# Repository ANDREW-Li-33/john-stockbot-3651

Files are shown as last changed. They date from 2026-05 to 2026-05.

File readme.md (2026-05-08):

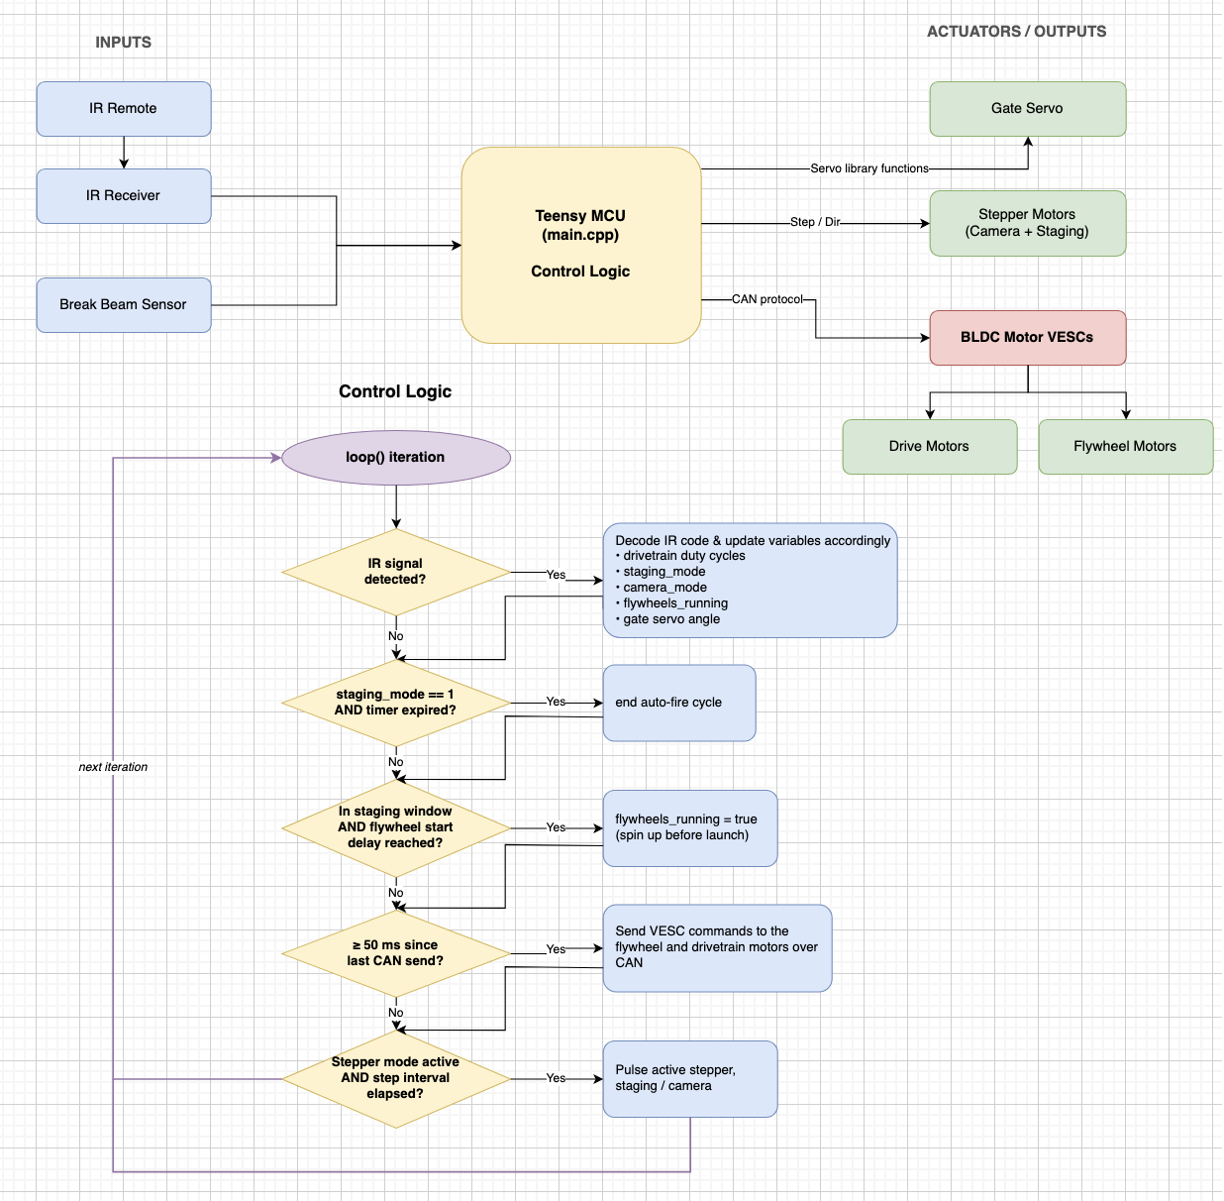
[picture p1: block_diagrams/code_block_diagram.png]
code block diagram

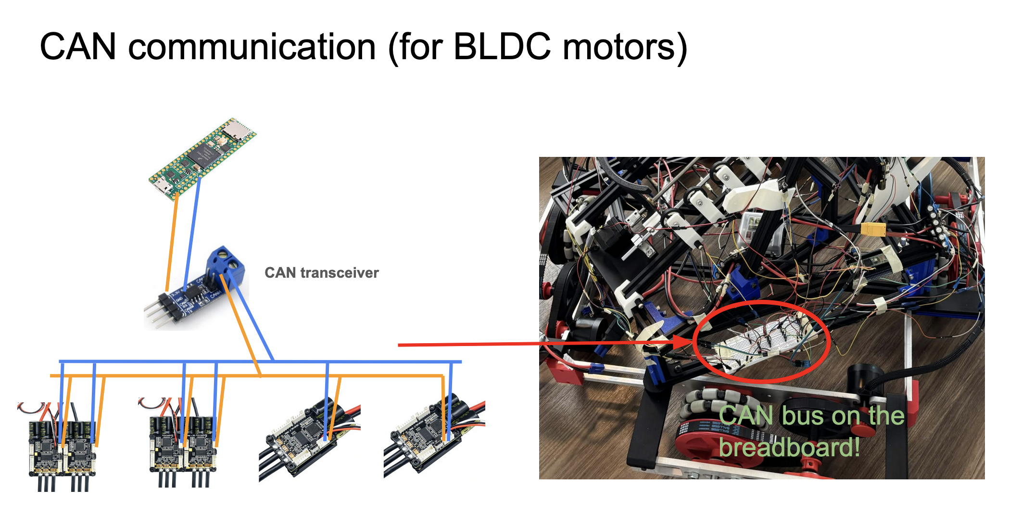
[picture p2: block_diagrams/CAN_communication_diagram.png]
CAN communication block diagram

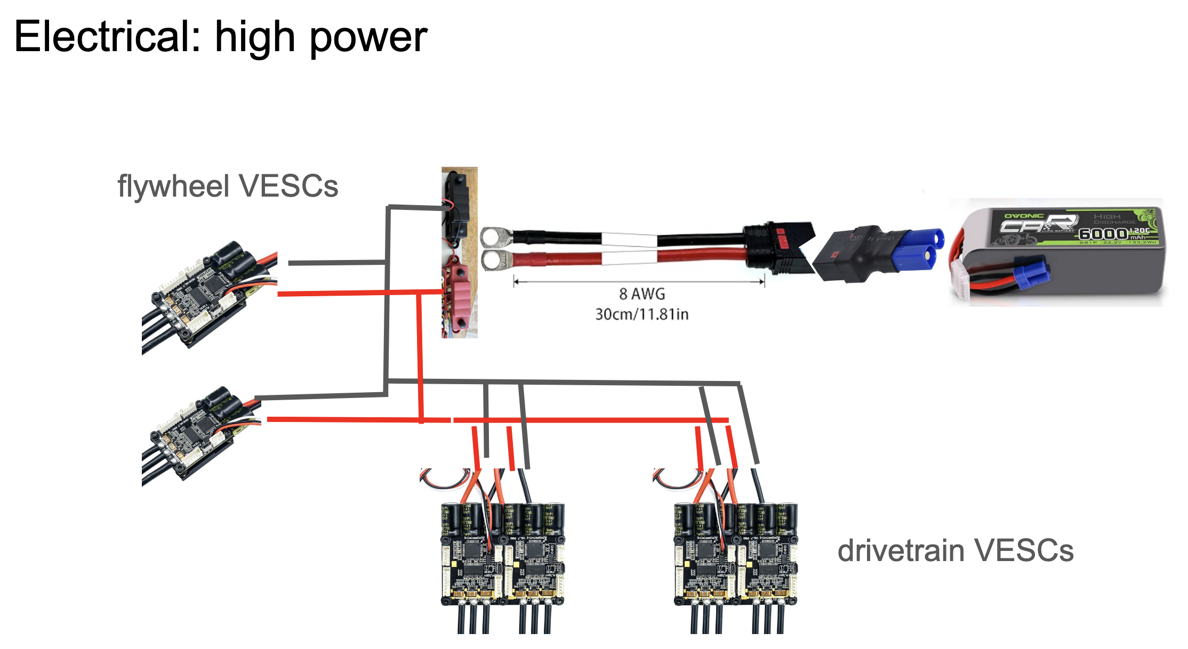
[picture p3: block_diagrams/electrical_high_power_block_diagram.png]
electrical high power block diagram

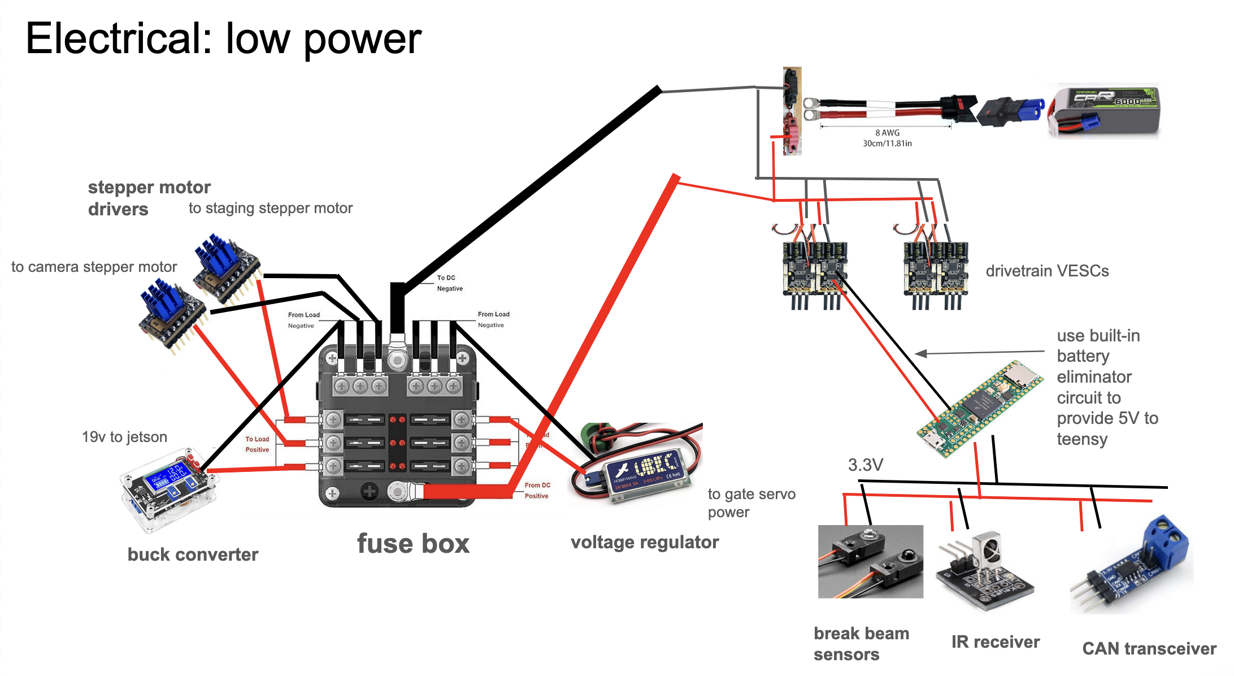
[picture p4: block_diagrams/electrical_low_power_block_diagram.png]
electrical low power block diagram


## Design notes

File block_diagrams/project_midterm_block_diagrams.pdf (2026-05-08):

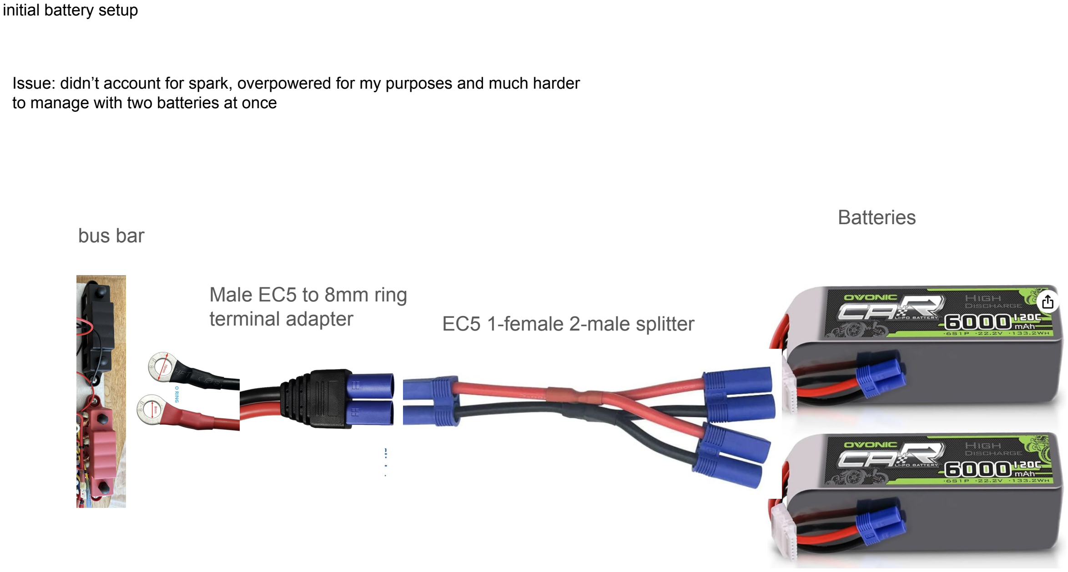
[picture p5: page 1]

initial battery setup

### Male EC5 to 8mm ring terminal adapter

### Batteries

### EC5 1-female 2-male splitter

### bus bar

Issue: didn’t account for spark, overpowered for my purposes and much harder to manage with two batteries at once

## new battery setup:

## - battery -> ec5 female - ec5 male -> QS8-S female - QS8-S female-> QS8-S male - QS8-S female -> ring terminal - ring terminal -> bus bar

# drivetrain escs to bus bar:

# - XT90 to ring terminal

# flywheel escs to bus bar:

# - bare wire to ring terminal - ring terminal to bus bar

# new battery setup

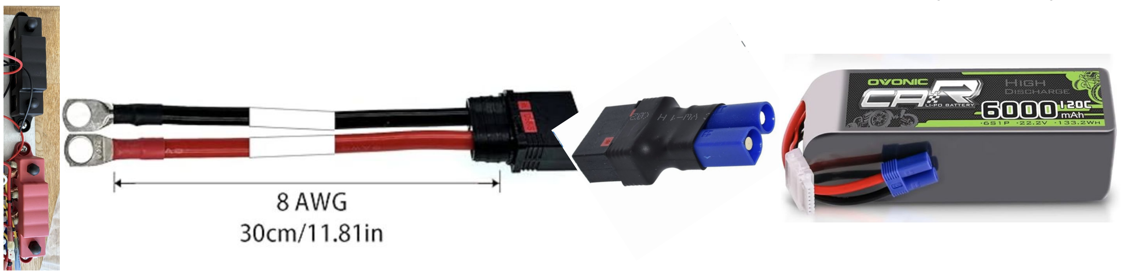
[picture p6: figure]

only one battery

QS8-S connectors.

- built-in anti-spark
- rated for up to 300A continuous

# New power distribution setup

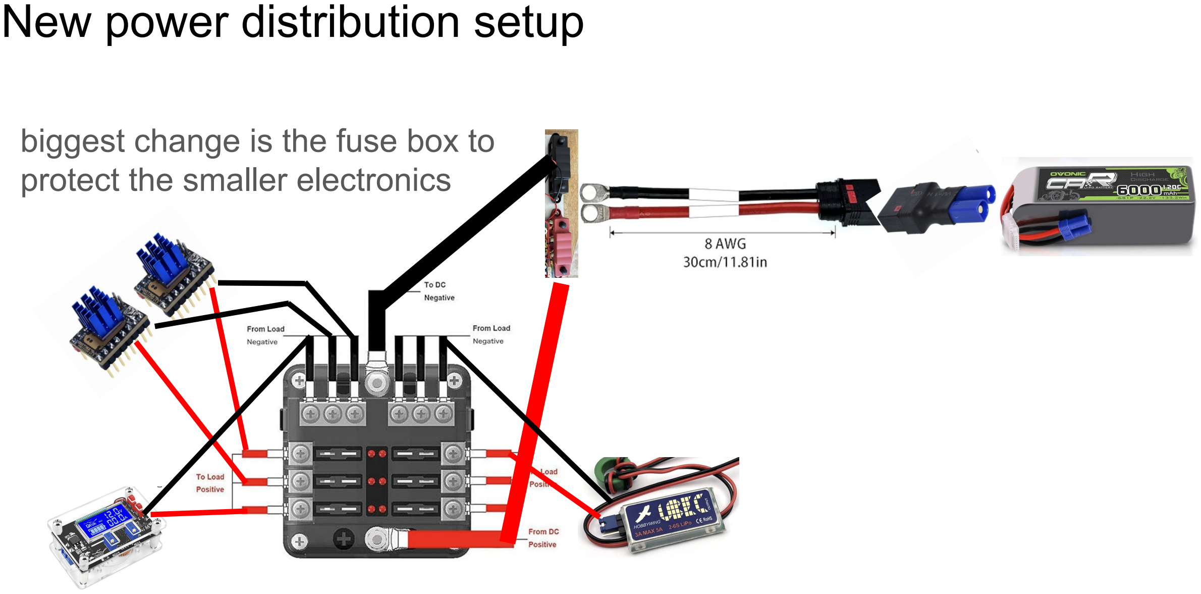
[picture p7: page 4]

# biggest change is the fuse box to protect the smaller electronics

# cut the copper trace between Vin and Vusb on the teensy so that i can have the battery powering the teensy and view the serial output through usb at the same time

# from laptop

## note: use protoboard and dupont connectors

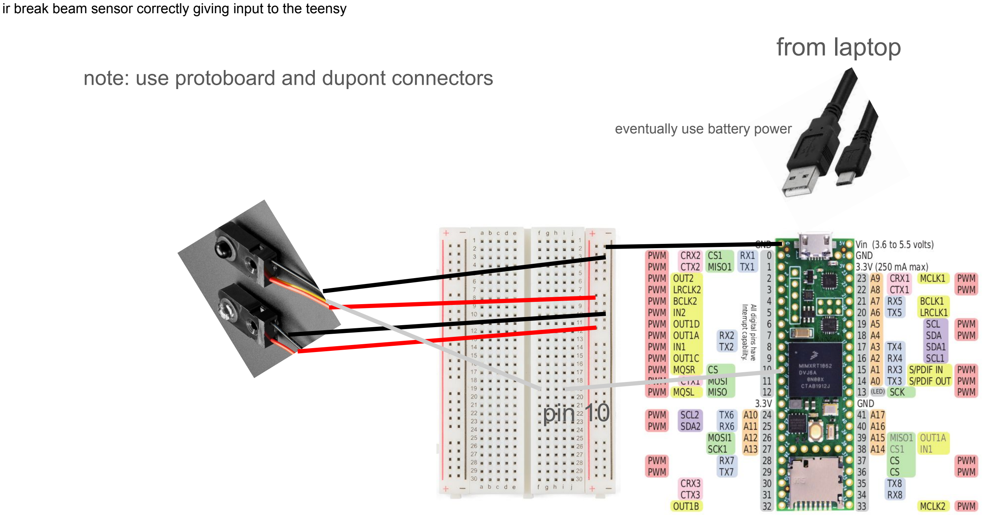
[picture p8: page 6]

ir break beam sensor correctly giving input to the teensy

# pin 10

eventually use battery power

## remote control working with the teensy

# from laptop

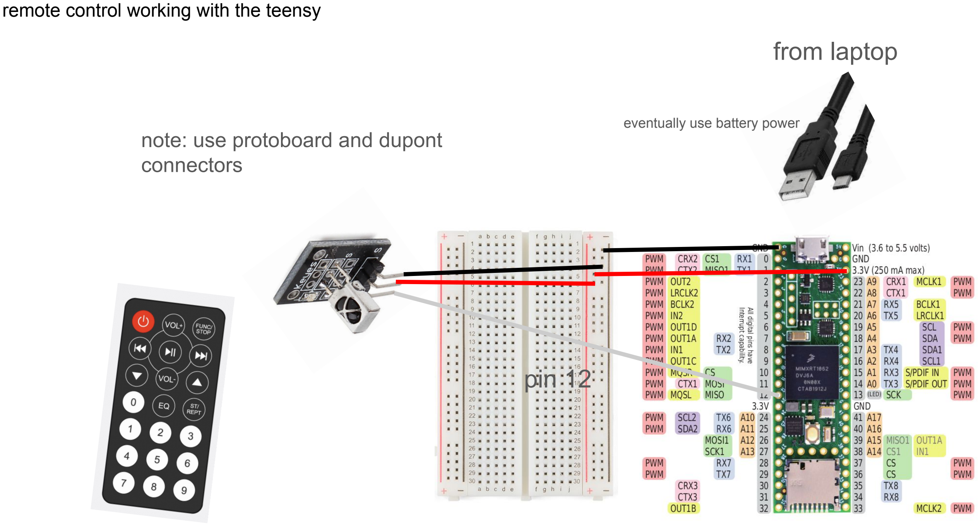
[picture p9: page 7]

# pin 12

eventually use battery power

## note: use protoboard and dupont connectors

## The servo motor moving using the remote control

## note: use protoboard and dupont

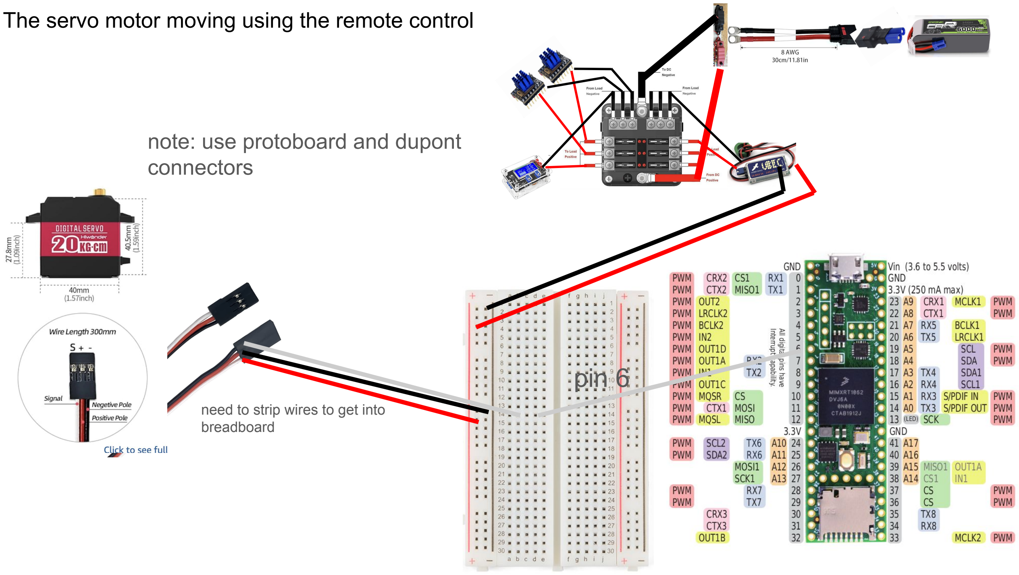
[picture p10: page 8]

need to strip wires to get into breadboard

# pin 6

## connectors

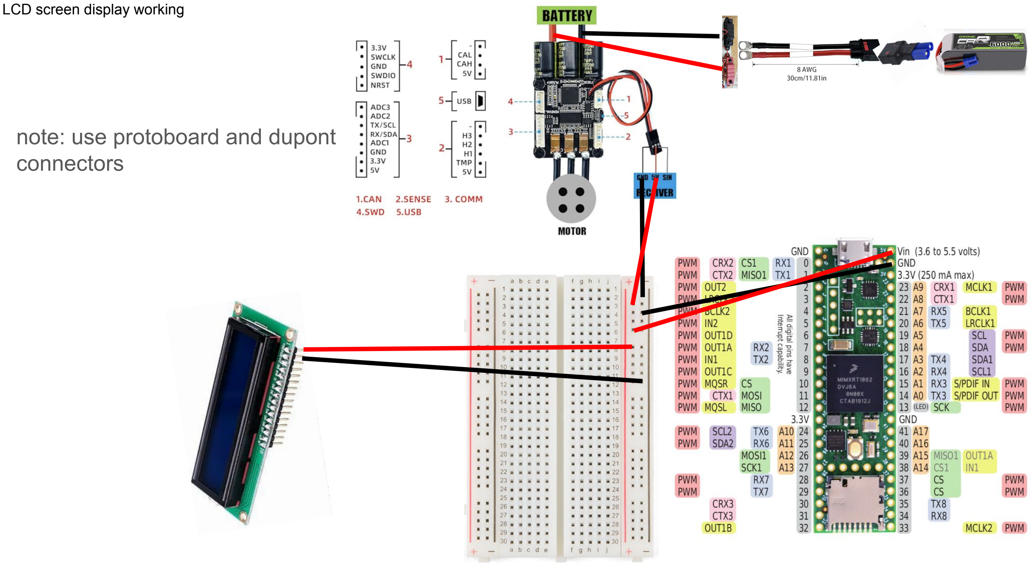
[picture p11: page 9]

LCD screen display working

## note: use protoboard and dupont connectors

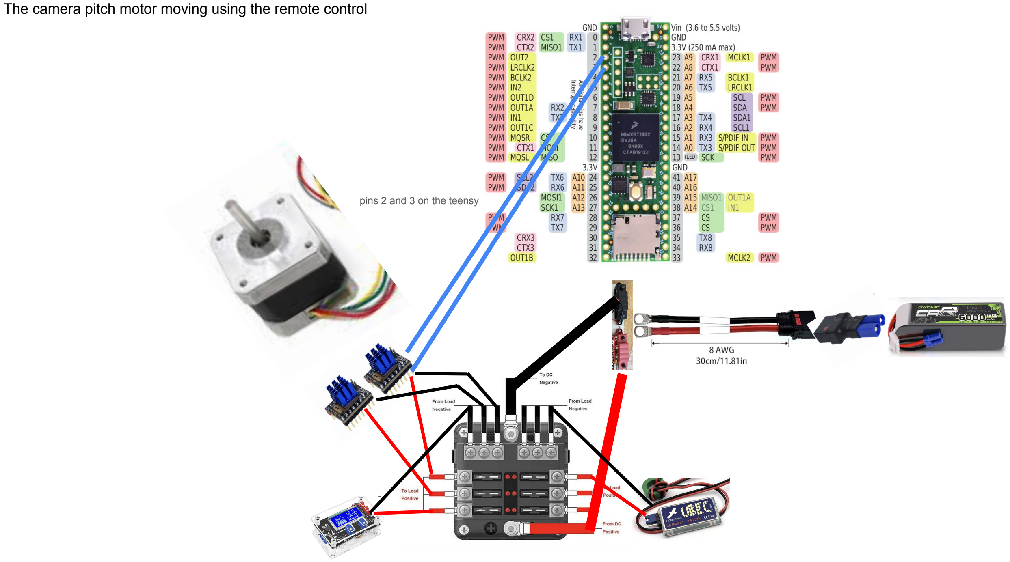
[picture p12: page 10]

The camera pitch motor moving using the remote control

pins 2 and 3 on the teensy

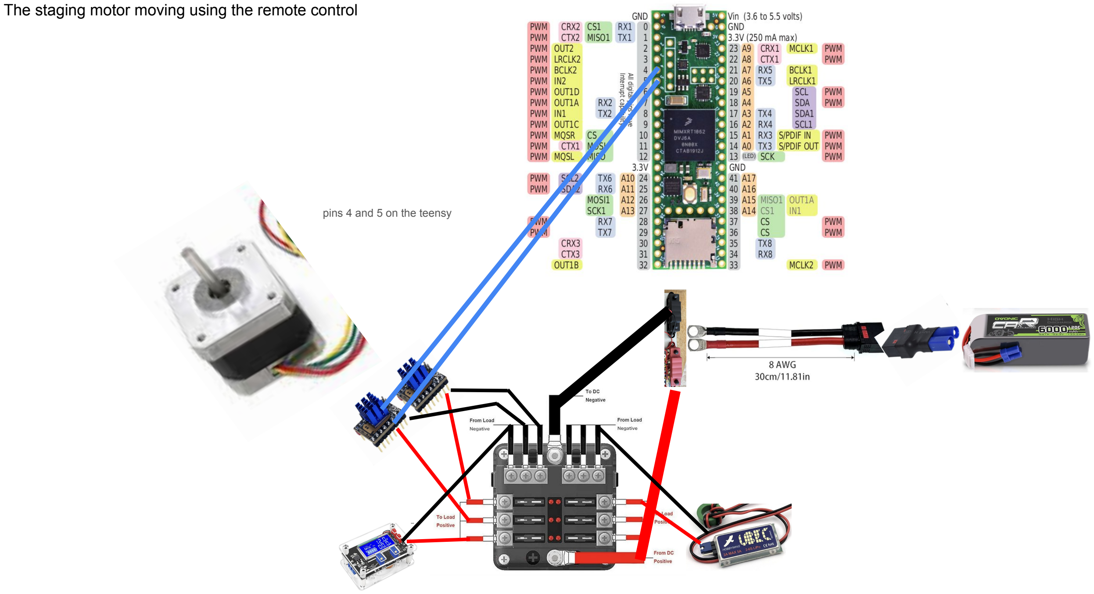
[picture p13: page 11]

The staging motor moving using the remote control

pins 4 and 5 on the teensy

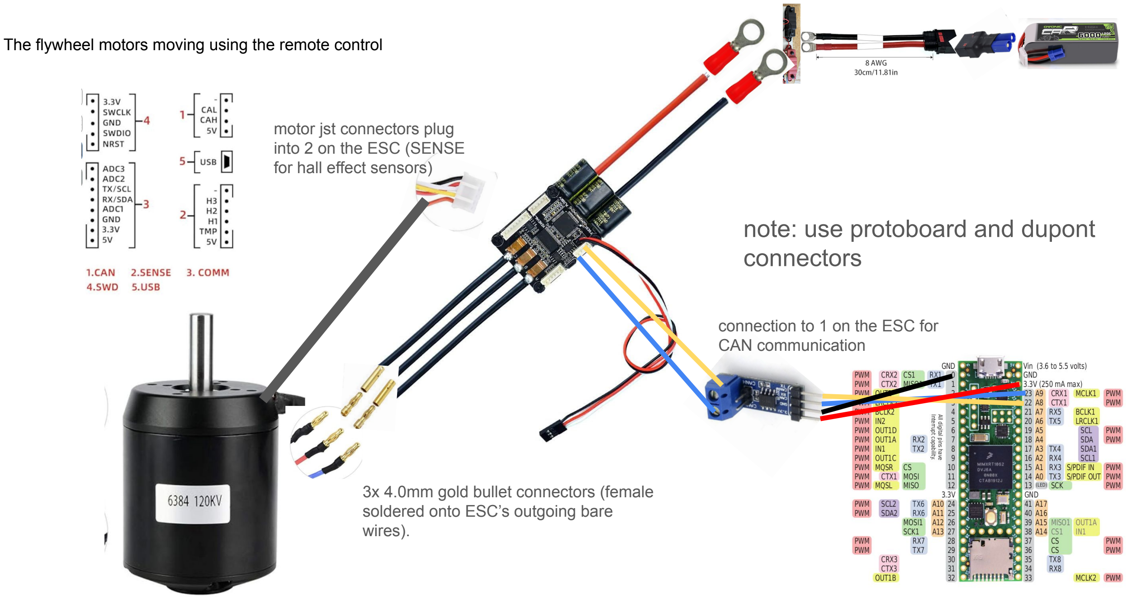
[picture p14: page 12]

The flywheel motors moving using the remote control

3x 4.0mm gold bullet connectors (female soldered onto ESC’s outgoing bare wires).

motor jst connectors plug
into 2 on the ESC (SENSE
for hall effect sensors)

connection to 1 on the ESC for CAN communication

## note: use protoboard and dupont connectors

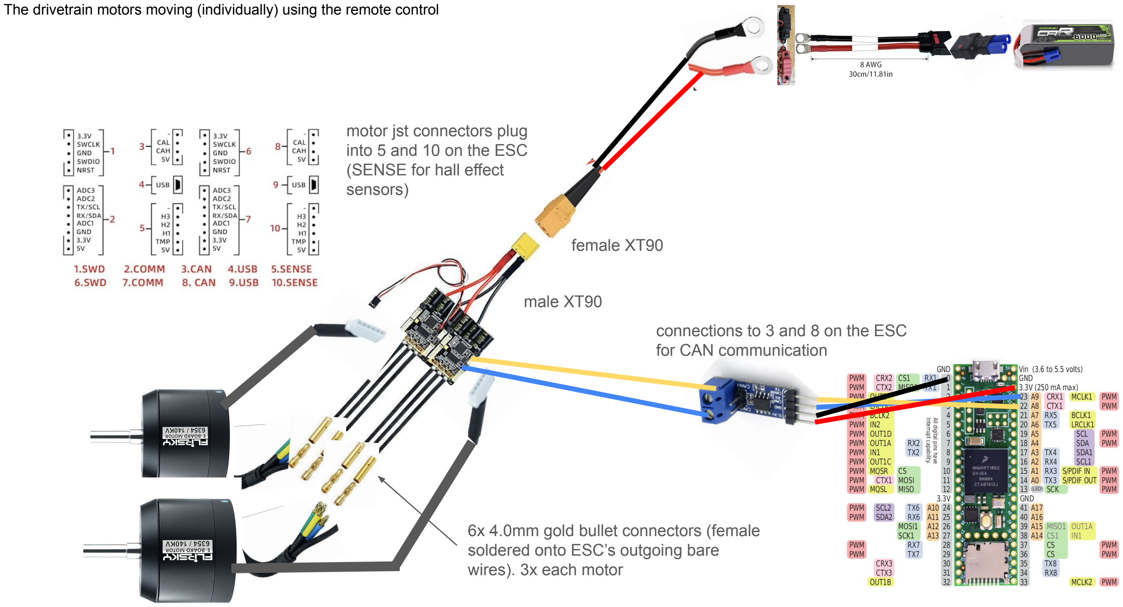
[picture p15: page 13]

The drivetrain motors moving (individually) using the remote control

male XT90

female XT90

6x 4.0mm gold bullet connectors (female soldered onto ESC’s outgoing bare wires). 3x each motor

motor jst connectors plug
into 5 and 10 on the ESC
(SENSE for hall effect
sensors)

connections to 3 and 8 on the ESC for CAN communication

# stepper motor driver connections (camera pitch controller)

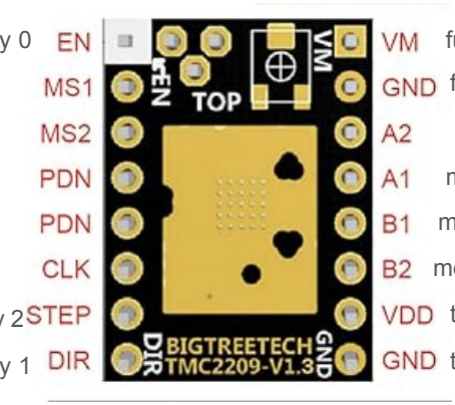
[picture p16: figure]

# fuse box

# fuse box

# teensy 3.3V

# teensy

# motor blue

# motor green

# motor red

# motor black

# teensy 1

# teensy 2

# teensy 0

# stepper motor driver connections (staging controller)

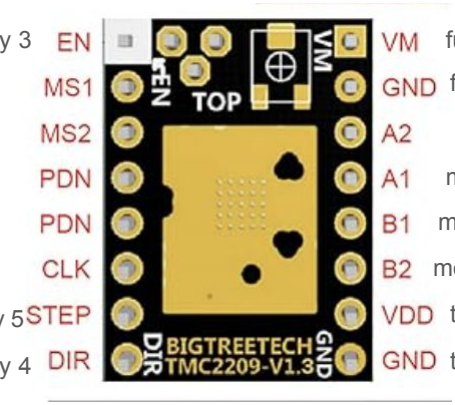
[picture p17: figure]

# fuse box

# fuse box

# teensy 3.3V

# teensy

# motor blue

# motor green

# motor red

# motor black

# teensy 4

# teensy 5

# teensy 3

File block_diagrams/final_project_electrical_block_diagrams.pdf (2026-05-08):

# Electrical: high power

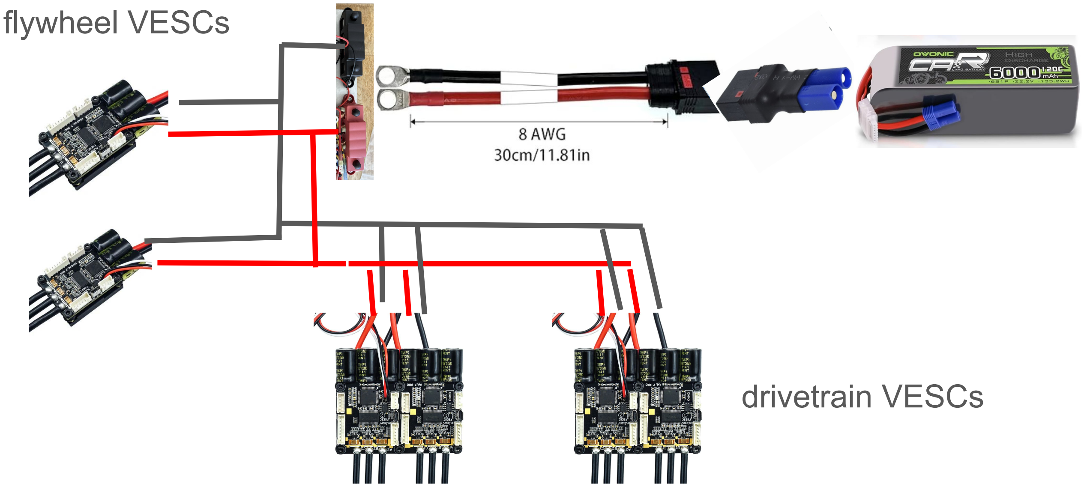
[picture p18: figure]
flywheel VESCs; drivetrain VESCs

# Electrical: low power

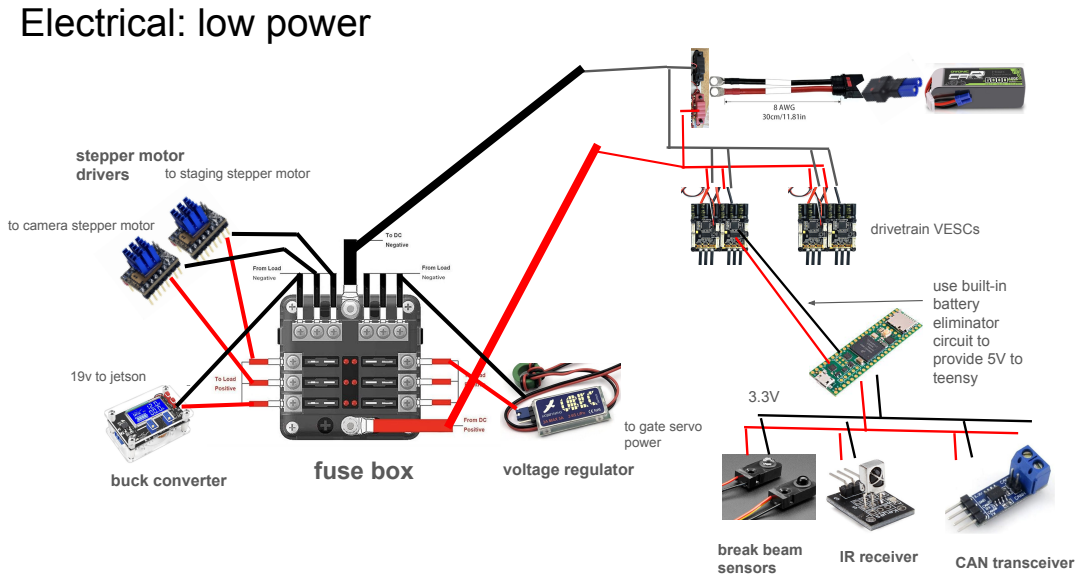
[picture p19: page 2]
drivetrain VESCs; 19v to jetson; stepper motor drivers; voltage regulator

to staging stepper motor

to camera stepper motor

use built-in
battery
eliminator
circuit to
provide 5V to
teensy

to gate servo
power

fuse box buck converter

CAN transceiver IR receiver break beam
sensors

# CAN communication (for BLDC motors)

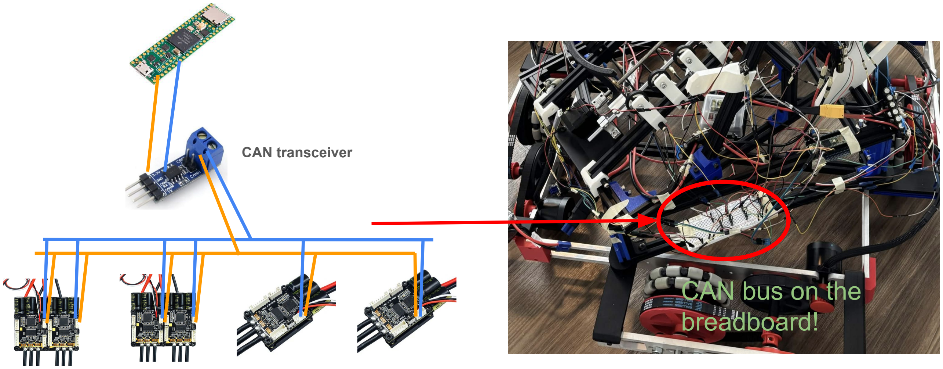
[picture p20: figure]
CAN transceiver; CAN bus on the breadboard!

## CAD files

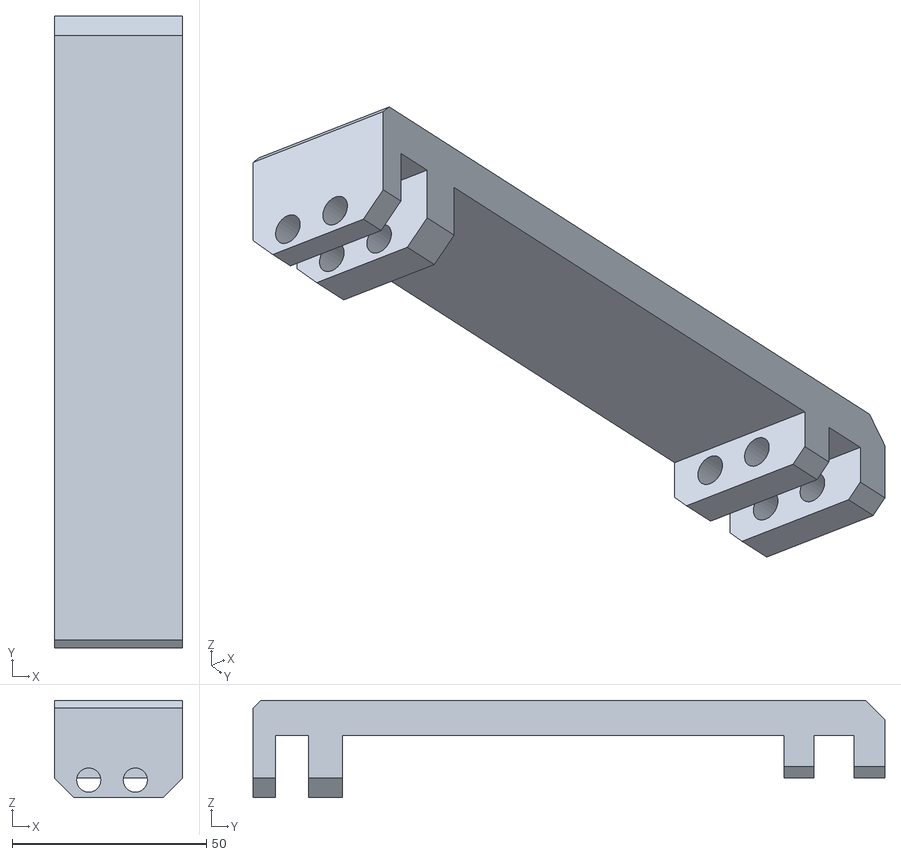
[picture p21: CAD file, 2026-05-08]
CAD files/drivetrain printed parts/large_motor_side_connector.stl
33.0 x 162.7 x 25.0

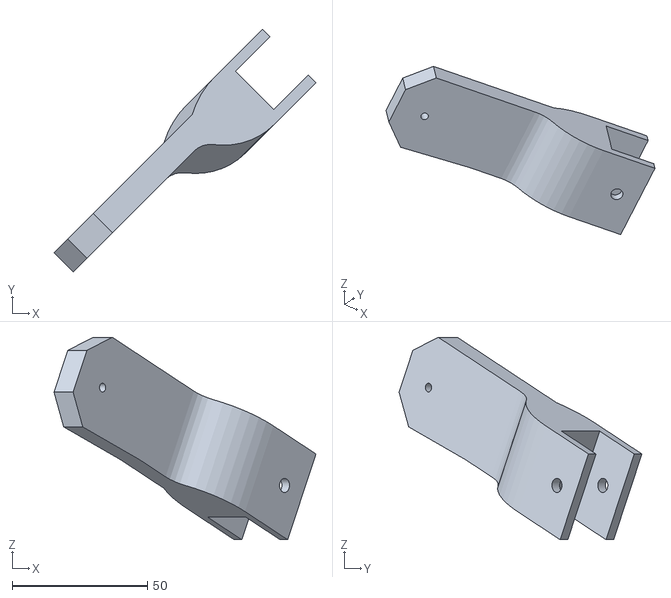
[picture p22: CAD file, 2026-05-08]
CAD files/final project 3651/break_beam_mount.stl
96.9 x 89.9 x 74.9

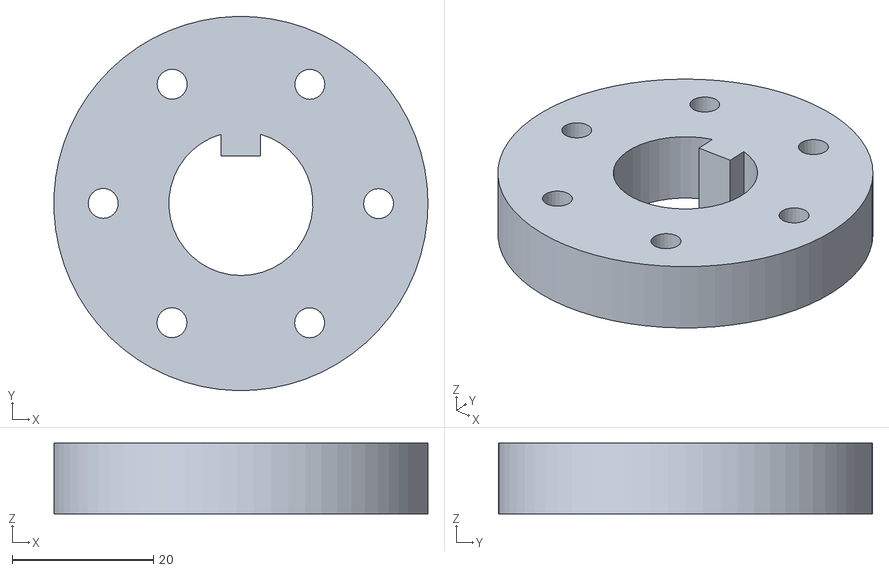
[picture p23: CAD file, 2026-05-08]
CAD files/flywheel printed parts/wheel attachment.stl
53.0 x 53.0 x 10.0

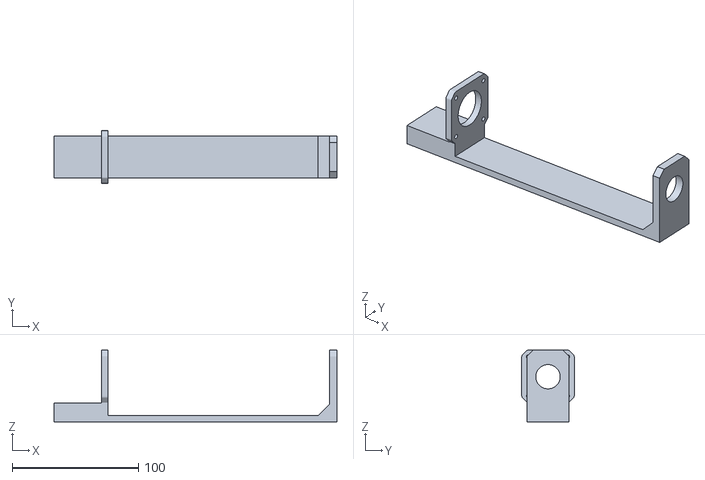
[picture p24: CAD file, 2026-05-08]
CAD files/john-stockbot-3dprint_camera/base.stl
224.2 x 41.6 x 56.8

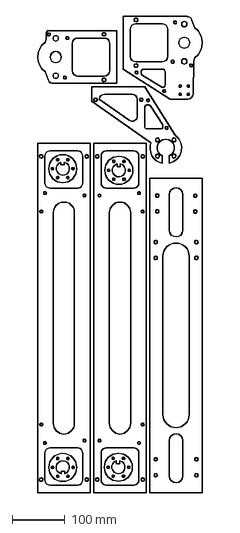
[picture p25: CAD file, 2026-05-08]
CAD files/john_stockbot_waterjet/sketch_no_points.dxf
312.7 x 903.2 mm

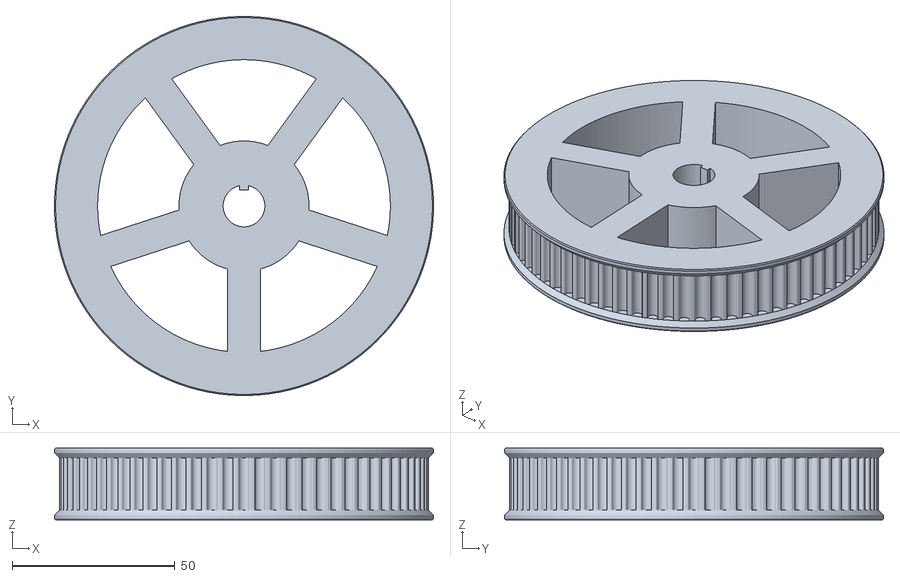
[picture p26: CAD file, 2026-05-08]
CAD files/drivetrain printed parts/intermediate_72T_pulley.stl
116.6 x 116.6 x 22.0

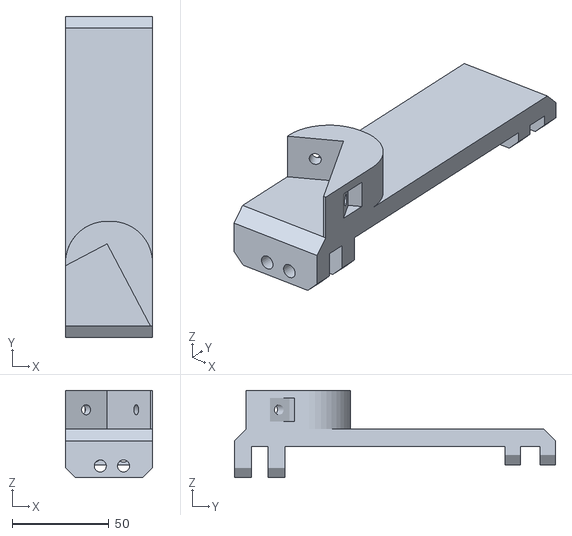
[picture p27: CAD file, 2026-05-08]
CAD files/final project 3651/thick outer plate.stl
45.0 x 165.7 x 45.0

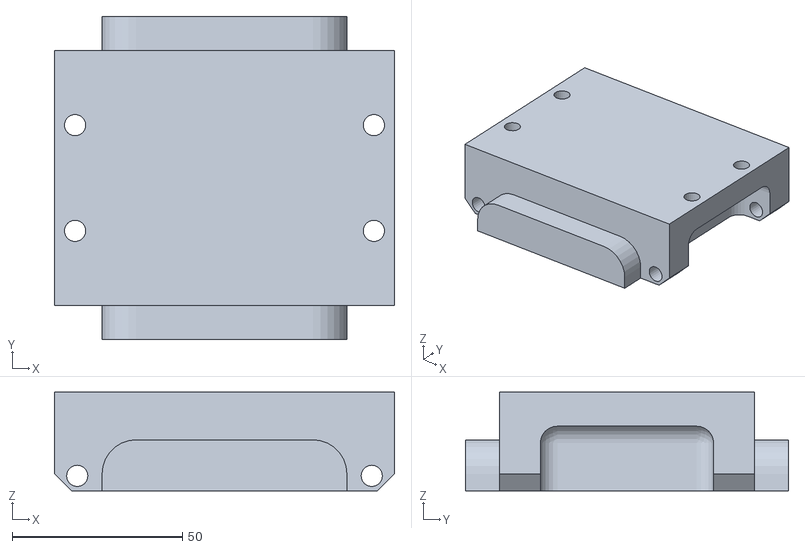
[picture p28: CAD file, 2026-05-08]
CAD files/flywheel printed parts/no motor side bracket.stl
100.0 x 95.0 x 29.0

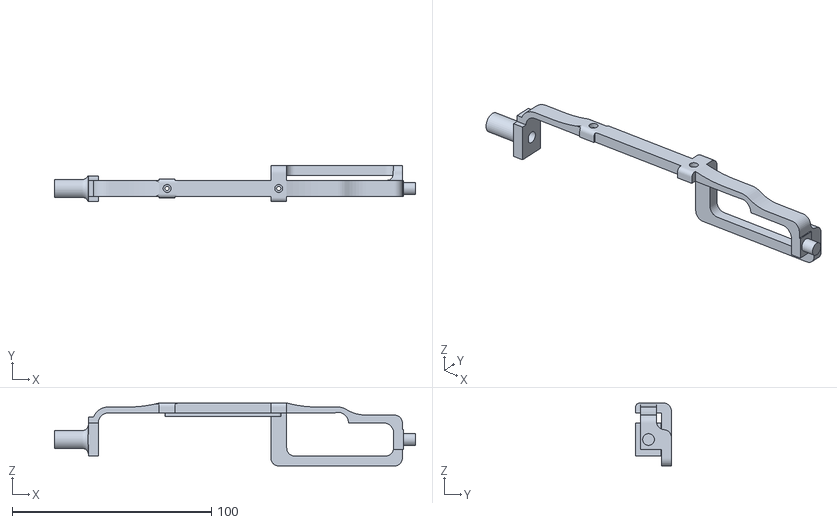
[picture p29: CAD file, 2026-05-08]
CAD files/john-stockbot-3dprint_camera/camera_attachment.stl
181.2 x 18.0 x 31.6

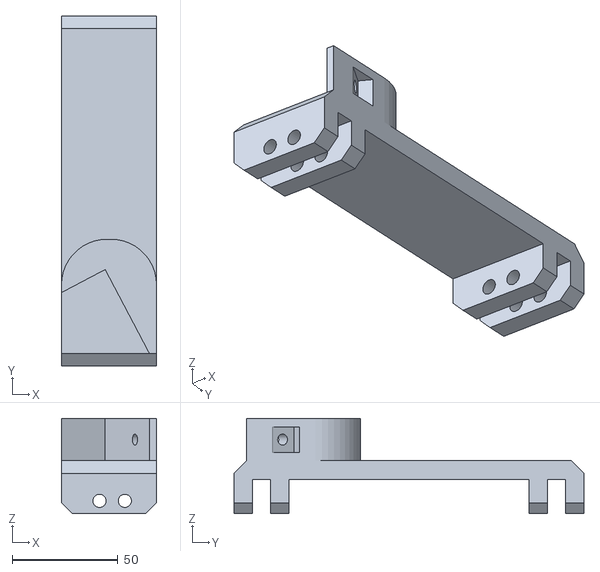
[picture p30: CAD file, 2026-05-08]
CAD files/drivetrain printed parts/small_non_motor_side_connector.stl
45.0 x 165.7 x 45.0

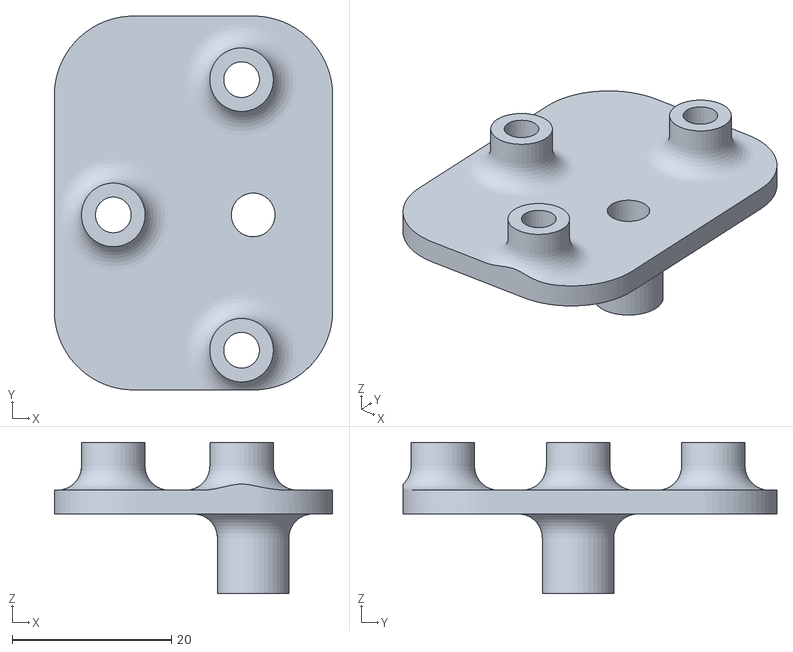
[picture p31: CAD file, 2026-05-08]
CAD files/final project 3651/single_esc_testing_plate.stl
35.0 x 47.0 x 19.0

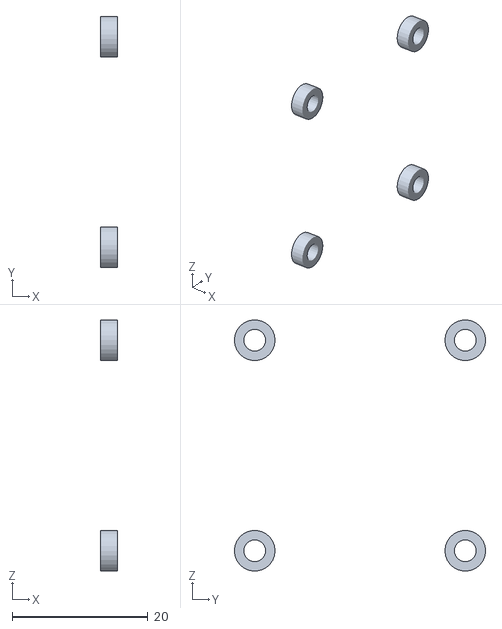
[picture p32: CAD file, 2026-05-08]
CAD files/john-stockbot-3dprint_camera/spaceres.stl
2.50 x 37.0 x 37.0

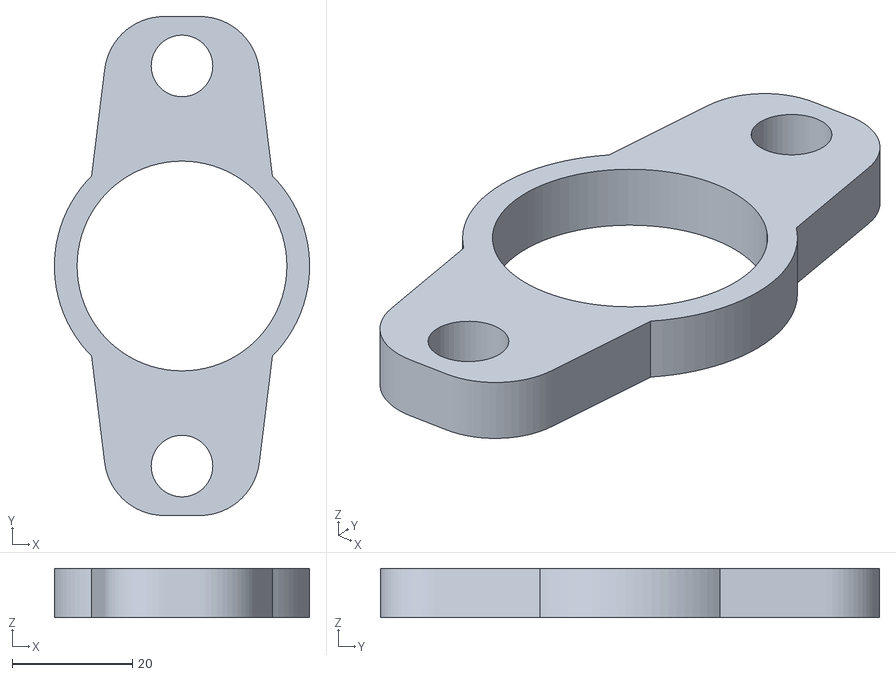
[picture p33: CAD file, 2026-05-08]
CAD files/drivetrain printed parts/ball bearing mount.stl
42.5 x 83.1 x 8.20

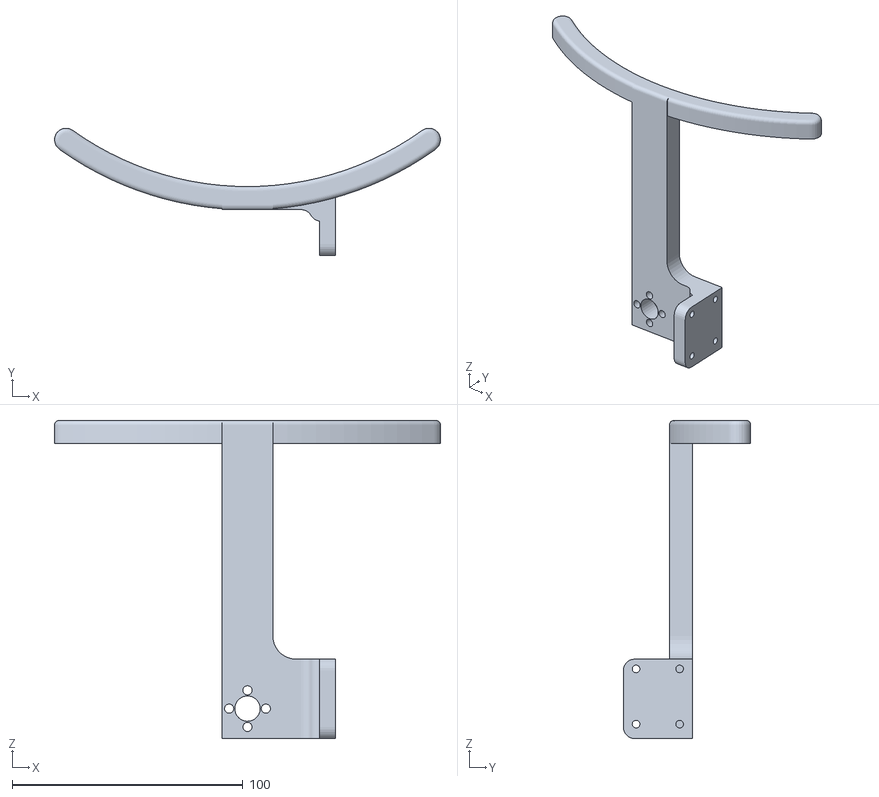
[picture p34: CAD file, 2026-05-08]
CAD files/final project 3651/push stick.stl
167.4 x 55.3 x 138.0

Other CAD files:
CAD files/flywheel printed parts/motor side inner bracket.stl
CAD files/drivetrain printed parts/wheel_90T_pulley.stl
CAD files/final project 3651/lighter_converyor_wheel.stl
CAD files/drivetrain printed parts/4mm_high_spacer.stl
CAD files/drivetrain printed parts/intermediate_20T_pulley.stl
CAD files/drivetrain printed parts/large_non_motor_side_connector.stl
CAD files/final project 3651/battery_mount.stl
CAD files/final project 3651/bottom_conveyor_mount.stl
CAD files/final project 3651/bus_bar_holder.stl
CAD files/final project 3651/conveyor_mount.stl
CAD files/final project 3651/conveyor_wheel.stl
CAD files/final project 3651/dual_drivetrain_esc_testing_plate.stl
CAD files/final project 3651/fuse_box_mount.stl
CAD files/final project 3651/gate_stick.stl
CAD files/final project 3651/lighter_converyor_wheel.f3d
CAD files/final project 3651/m5_spacer.stl
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

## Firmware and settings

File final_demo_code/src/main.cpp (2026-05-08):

#include <Arduino.h>
#include <FlexCAN_T4.h>
#include <Servo.h>

const byte TEENSY_LED_PIN = 13; // used for debugging break beam sensor

// SENSORS
const byte IR_RECEIVER_PIN = 12;
const byte BREAK_BEAM_PIN = 10;



// ACTUATION
const byte SERVO_PIN = 6;

// camera stepper motor
const byte CAM_STEPPER_EN_PIN = 0;
const byte CAM_STEPPER_DIR_PIN = 1;
const byte CAM_STEPPER_STEP_PIN = 2;

// staging stepper motor
const byte STAGE_STEPPER_EN_PIN = 3;
const byte STAGE_STEPPER_DIR_PIN = 4;
const byte STAGE_STEPPER_STEP_PIN = 5;


// BLDC motor control (flywheel and drivetrain)
const uint32_t CAN_PACKET_DUTY_CYCLE = 0;
const uint32_t CAN_PACKET_CURRENT = 1;

const byte TOP_FLY_CAN_ADDR = 27;
const byte BOT_FLY_CAN_ADDR = 91;

const byte DRIVE_FR_CAN_ADDR = 84;
const byte DRIVE_BL_CAN_ADDR = 79;
const byte DRIVE_FL_CAN_ADDR = 94;
const byte DRIVE_BR_CAN_ADDR = 72;

float duty_drive_FR = 0.0;
float duty_drive_BL = 0.0;
float duty_drive_FL = 0.0;
float duty_drive_BR = 0.0;

bool flywheels_running = false;

// durations in milliseconds
const uint16_t FLYWHEEL_START_DELAY = 26000;
const unsigned long STAGING_FORWARD_DURATION = 33000;

uint8_t staging_mode = 0;
unsigned long staging_forward_stop_time = 0; // the time in the future when the staging motor should stop

uint8_t camera_mode = 0;
unsigned long last_camera_step_time = 0;

unsigned long last_step_time = 0;
const unsigned long STEP_INTERVAL = 800;

// CAN communication with the BLDC motors
unsigned long lastCanSend = 0;
const unsigned long CAN_INTERVAL = 50;


FlexCAN_T4<CAN1, RX_SIZE_256, TX_SIZE_16> can_bus; // setting CAN1 uses the first set of CAN communication pins, 22 and 23

// gate servo control
int8_t servo_angle = 90;
Servo gateServo;

// break beam sensor states
int last_beam_state = HIGH;

// IR REMOTE CODES
const unsigned long IR_0 = 0xFF6897;
const unsigned long IR_POWER = 0xFFA25D;
const unsigned long IR_FAST_BACK = 0xFF22DD;
const unsigned long IR_FAST_FWD = 0xFFC23D;
const unsigned long IR_VOL_PLUS = 0xFF629D;
const unsigned long IR_VOL_MINUS = 0xFFA857;
const unsigned long IR_UP = 0xFF906F;
const unsigned long IR_DOWN = 0xFFE01F;
const unsigned long IR_PLAY = 0xFF02FD;
const unsigned long IR_FUNC_STOP = 0xFFE21D;
const unsigned long IR_7 = 0xFF42BD;
const unsigned long IR_8 = 0xFF4AB5;
const unsigned long IR_9 = 0xFF52AD;


// returns the length of a specified IR signal, length determines if the incoming signals represent a header
unsigned long readPulse(int level, unsigned long timeout = 20000) {
    unsigned long start = micros();
    while (digitalRead(IR_RECEIVER_PIN) == level) {
        // if the length of the signal is longer than 20000 microseconds, return 0
        // this prevents the code from hanging indefinitely if no state change occurs
        if (micros() - start > timeout) {
            return 0;
        }
    }
    return micros() - start;
}


void setVescDuty(uint8_t id, float duty) {
    CAN_message_t msg;

    msg.id = (CAN_PACKET_DUTY_CYCLE << 8) | id; // unique CAN id
    msg.flags.extended = 1;
    msg.len = 4;

    int32_t sendValue = (int32_t)(duty * 100000.0);

    // slice the message into four pieces to be able to fit into the msg array, MSB first
    msg.buf[0] = (sendValue >> 24) & 0xFF;
    msg.buf[1] = (sendValue >> 16) & 0xFF;
    msg.buf[2] = (sendValue >> 8) & 0xFF;
    msg.buf[3] = sendValue & 0xFF;

    can_bus.write(msg);
}

void setVescCurrent(uint8_t id, float current) {
  CAN_message_t msg;

  msg.id = (CAN_PACKET_CURRENT << 8) | id;
  msg.flags.extended = 1;
  msg.len = 4;

  int32_t sendValue = (int32_t)(current * 1000.0);

  msg.buf[0] = (sendValue >> 24) & 0xFF;
  msg.buf[1] = (sendValue >> 16) & 0xFF;
  msg.buf[2] = (sendValue >> 8) & 0xFF;
  msg.buf[3] = sendValue & 0xFF;

  can_bus.write(msg);
}

void stopAllDriveMotors() {
    duty_drive_FR = 0.0;
    duty_drive_BL = 0.0;
    duty_drive_FL = 0.0;
    duty_drive_BR = 0.0;
}

void sendMotorDuty(uint8_t id, float duty) {
    if (duty != 0.0) {
        setVescDuty(id, duty);
    } else {
        setVescCurrent(id, 0.0); // allow the motor to coast rather than actively fight movement
    }
}


void setup() {

    pinMode(IR_RECEIVER_PIN, INPUT);
    pinMode(BREAK_BEAM_PIN, INPUT_PULLUP);
    pinMode(TEENSY_LED_PIN, OUTPUT);

    pinMode(CAM_STEPPER_EN_PIN, OUTPUT);
    pinMode(CAM_STEPPER_DIR_PIN, OUTPUT);
    pinMode(CAM_STEPPER_STEP_PIN, OUTPUT);
    digitalWrite(CAM_STEPPER_EN_PIN, LOW);

    pinMode(STAGE_STEPPER_EN_PIN, OUTPUT);
    pinMode(STAGE_STEPPER_DIR_PIN, OUTPUT);
    pinMode(STAGE_STEPPER_STEP_PIN, OUTPUT);
    digitalWrite(STAGE_STEPPER_EN_PIN, LOW);

    gateServo.attach(SERVO_PIN);
    gateServo.write(servo_angle);

    can_bus.begin();
    can_bus.setBaudRate(500000);
}

void loop() {
    // IR signal detection
    if (digitalRead(IR_RECEIVER_PIN) == LOW) {
        unsigned long pulse_low_time = readPulse(LOW);
        unsigned long pulse_high_time = readPulse(HIGH);

        // a repeat code uses a shorter 2250us high pulse
        if (pulse_low_time > 8000 && pulse_high_time > 2000 && pulse_high_time < 3000) {
        } else if (pulse_low_time > 8000 && pulse_high_time > 4000) {
            // system knows that a new command is about to come in
            unsigned long code = 0;

            // now decode the bits
            // the "code" variable is what cumulatively stores the ir code coming in
            for (int i = 0; i < 32; i++) {
                readPulse(LOW); // every bit starts with a space, so we ignore that, what we want is in the high signal
                unsigned long bitHigh = readPulse(HIGH);
                code <<= 1; // make room for the new bit at the end
                if (bitHigh > 1000) {
                code |= 1;  // add a 1 to the end of the code
                }
            }


            switch (code)
            {
            case IR_FAST_FWD:
                float val = (duty_drive_FL != 0.0) ? 0.0 : 0.1;
                duty_drive_FL = val;
                duty_drive_BR = val;
                break;
            
            case IR_FAST_BACK:
                float val = (duty_drive_FL != 0.0) ? 0.0 : -0.1;
                duty_drive_FL = val;
                duty_drive_BR = val;
                break;

            case IR_VOL_PLUS:
                float val = (duty_drive_FR != 0.0) ? 0.0 : 0.1;
                duty_drive_FR = val;
                duty_drive_BL = (val == 0.0) ? 0.0 : -0.1;
                break;

            case IR_VOL_MINUS:
                float val = (duty_drive_FR != 0.0) ? 0.0 : -0.1;
                duty_drive_FR = val;
                duty_drive_BL = (val == 0.0) ? 0.0 : 0.1;
                break;

            case IR_UP:
                float val = (duty_drive_FL != 0.0) ? 0.0 : 0.1;
                duty_drive_FL = (val == 0.0) ? 0.0 : -val;
                duty_drive_BR = val;
                break;

            case IR_DOWN:
                float val = (duty_drive_FR != 0.0) ? 0.0 : 0.1;
                duty_drive_FR = val;
                duty_drive_BL = val;
                break;

            case IR_PLAY:
                // HANDLE BEGINNING THE AUTOMATIC STAGING
                if (digitalRead(BREAK_BEAM_PIN) == LOW) {
                    staging_mode = 1;
                    flywheels_running = false;
                    staging_forward_stop_time = millis() + STAGING_FORWARD_DURATION;
                    digitalWrite(STAGE_STEPPER_DIR_PIN, LOW);

                    // open the gate
                    servo_angle = 0;
                    gateServo.write(servo_angle);
                }
                break;
            
            case IR_FUNC_STOP:
                if (staging_mode == 2) {
                    staging_mode = 0;
                } else {
                    staging_mode = 2;
                    digitalWrite(STAGE_STEPPER_DIR_PIN, HIGH);
                }
                break;

            case IR_7:
                // toggling gate servo angle
                servo_angle = (servo_angle == 90) ? 0 : 90;
                gateServo.write(servo_angle);
                break;

            case IR_8:
                if (camera_mode == 1) {
                    camera_mode = 0;
                } else {
                    camera_mode = 1;
                    digitalWrite(STAGE_STEPPER_DIR_PIN, LOW);
                }
                break;

            case IR_9:
                if (camera_mode == 2) {
                    camera_mode = 0;
                } else {
                    camera_mode = 2;
                    digitalWrite(STAGE_STEPPER_DIR_PIN, HIGH);
                }
                break;

            case IR_POWER:
                flywheels_running = false;
                break;

            case IR_0:
                stopAllDriveMotors();
                break;

            default:
                break;
            }
                   

        }
    }


    if (staging_mode == 1 && millis() >= staging_forward_stop_time) {
        // staging motor completes the 33 second run
        staging_mode = 0;
    }

    if (staging_mode == 1 && !flywheels_running && millis() >= staging_forward_stop_time - (STAGING_FORWARD_DURATION - FLYWHEEL_START_DELAY)) {
        flywheels_running = true;
    }

    // protect the CAN bus from behing overhwelmend, but also make sure that it stays active
    // send commands to the VESCs every 50 milliseconds
    if (millis() - lastCanSend >= CAN_INTERVAL) {
        lastCanSend = millis();

        // set to 20% speed if we want the flywheels to be running
        flywheels_running ? setVescDuty(TOP_FLY_CAN_ADDR, -0.2) : setVescCurrent(TOP_FLY_CAN_ADDR, 0.0);
        flywheels_running ? setVescDuty(BOT_FLY_CAN_ADDR, -0.2) : setVescCurrent(BOT_FLY_CAN_ADDR, 0.0);

        sendMotorDuty(DRIVE_FL_CAN_ADDR, duty_drive_FL);
        sendMotorDuty(DRIVE_BR_CAN_ADDR, duty_drive_BR);
        sendMotorDuty(DRIVE_FR_CAN_ADDR, duty_drive_FR);
        sendMotorDuty(DRIVE_BL_CAN_ADDR, duty_drive_BL);
    }


    // 1600 total pulse cycle 
    if (staging_mode != 0 && micros() - last_step_time >= STEP_INTERVAL) {
        last_step_time = micros();

        digitalWrite(STAGE_STEPPER_STEP_PIN, HIGH);
        delayMicroseconds(400);

        digitalWrite(STAGE_STEPPER_STEP_PIN, LOW);
        delayMicroseconds(400);
    }


    if (camera_mode != 0 && micros() - last_camera_step_time >= STEP_INTERVAL) {
        last_camera_step_time = micros();

        digitalWrite(CAM_STEPPER_STEP_PIN, HIGH);
        delayMicroseconds(400);

        digitalWrite(CAM_STEPPER_STEP_PIN, LOW);
        delayMicroseconds(400);
    }

    int beamState = digitalRead(BREAK_BEAM_PIN);

    // debugging
    if (beamState != last_beam_state) {
        if (beamState == LOW) {
            digitalWrite(TEENSY_LED_PIN, HIGH);
        } else {
            digitalWrite(TEENSY_LED_PIN, LOW);
        }
        last_beam_state = beamState;
    }
}
